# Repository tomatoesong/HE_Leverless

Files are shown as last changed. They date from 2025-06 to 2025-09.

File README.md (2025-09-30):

# HE_Leverless

# 🎮 Hall Effect Fighting Game Controller  

A custom-built **fighting game controller** featuring **Hall effect sensors** based on ESP32-S3 for ultra-durable, low latency performance. Designed for competitive play, modularity, and long-term reliability.  

---

## ✨ Features  

- 🕹 **Hall Effect Sensors** – no wear and tear from metal contact based switches 
- 🔧 **Modular Design** – easily replace buttons, just pull out an switch and snap in a new one
- ⚡ **Low Latency** – optimized input response at over 2000Hz polling with fully customizable actuation points for every switch!
- 🌐 **Web UI** - web based UI for customizing board on the go from anywhere without the need for connecting to a PC
- 💻 **Open Source Firmware** – customizable and community-driven  
- 🎨 **Custom Build** – unique layout and aesthetics  

---

## Custom PCB Layout  

| Front View |
|------------|
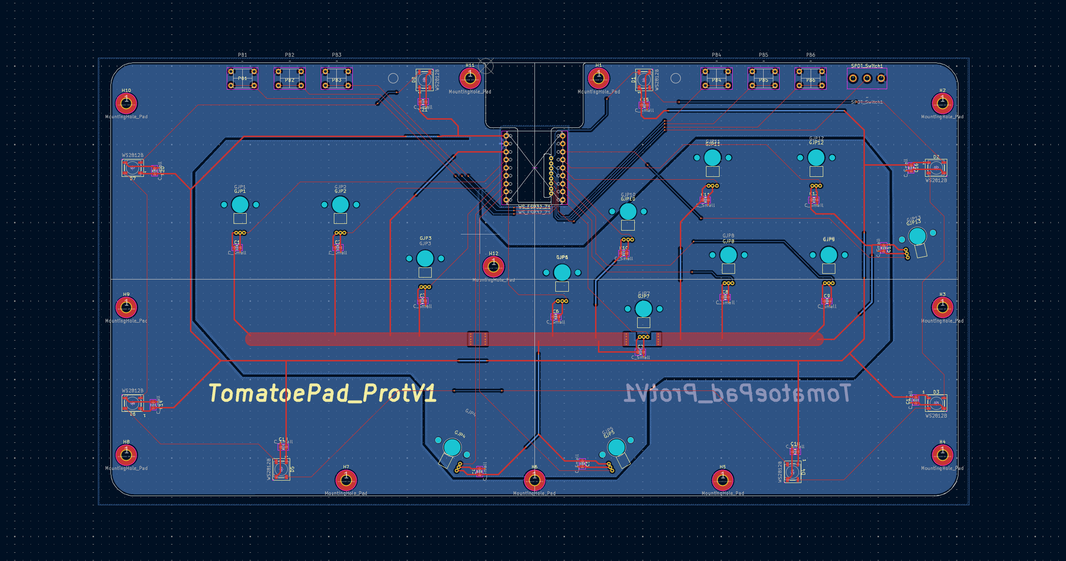
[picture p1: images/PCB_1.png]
|  |

Created Using KiCad and custom library and footprints!

### ✅ PCB Features
- Digital and Analog ground plane seperation
- Low count BOM
- One sided for easy of assembly on hot plate or oven!

---

## Web-Based UI 

| Startup View | Selection | Save with Ease |
|---|---|---|
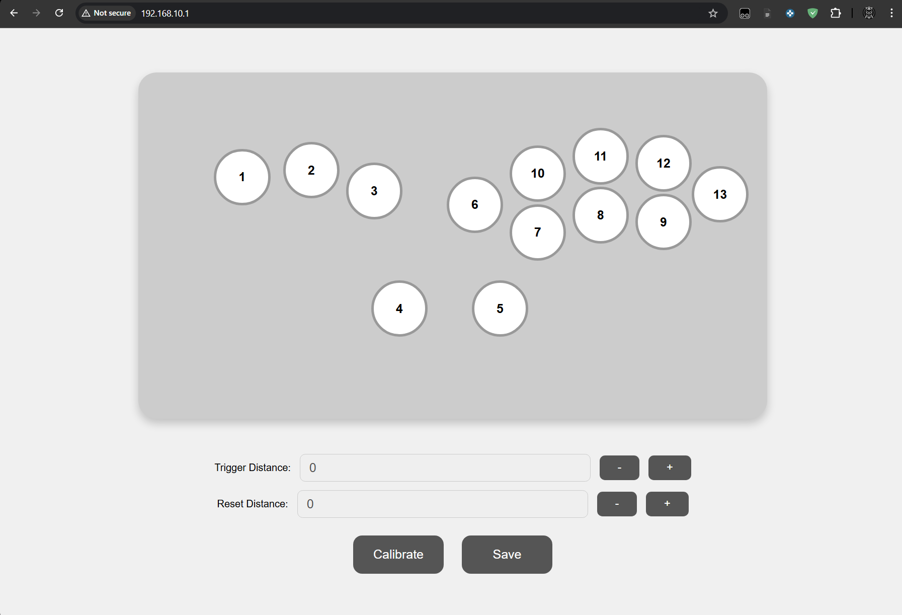
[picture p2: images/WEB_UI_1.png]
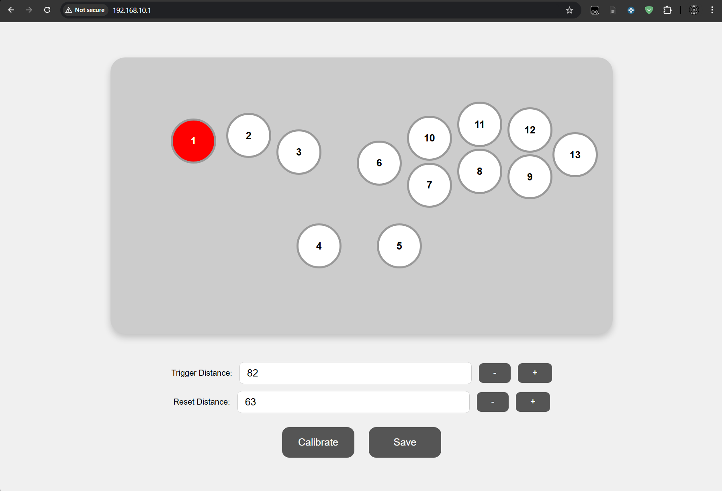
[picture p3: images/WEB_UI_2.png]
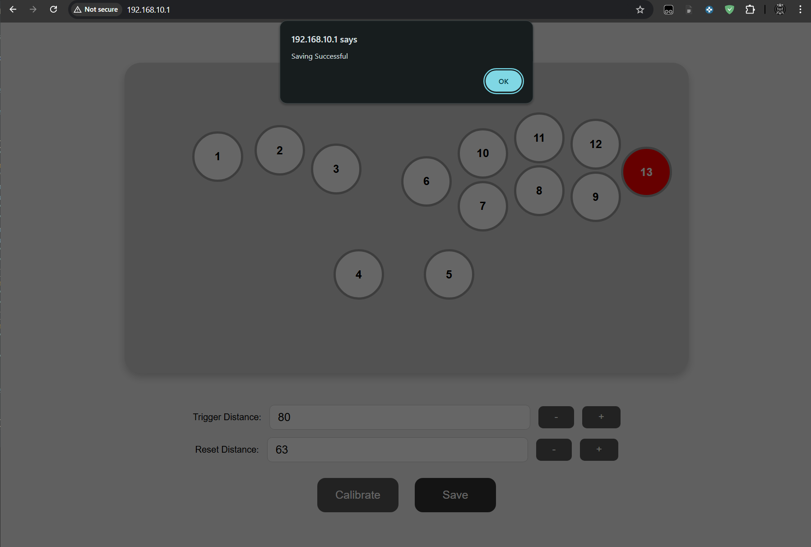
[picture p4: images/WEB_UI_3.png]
|  |  |  |

Fully integrated and interactable WEB UI from an embedded board

### ✅ WEB-UI Features
- Hosts it's own Wifi you connect to
- Access the configurator from any browser at 192.168.10.1
- Individually switch values can be set with intuitive UI indicating what button you are adjusting
- 5 MICRON steps of adjustment for HIGH precision customization

---

## CAD Model  
<!--
| Front View | Inside View | 
|---|---|
| ![Front View](images/CAD_MODEL_1.png) | ![WireFrame View](images/CAD_MODEL_2.png) |

*(Replace the image paths with your actual files, e.g., `/assets/controller-front.png`)*  
-->
| Front View |
|------------|
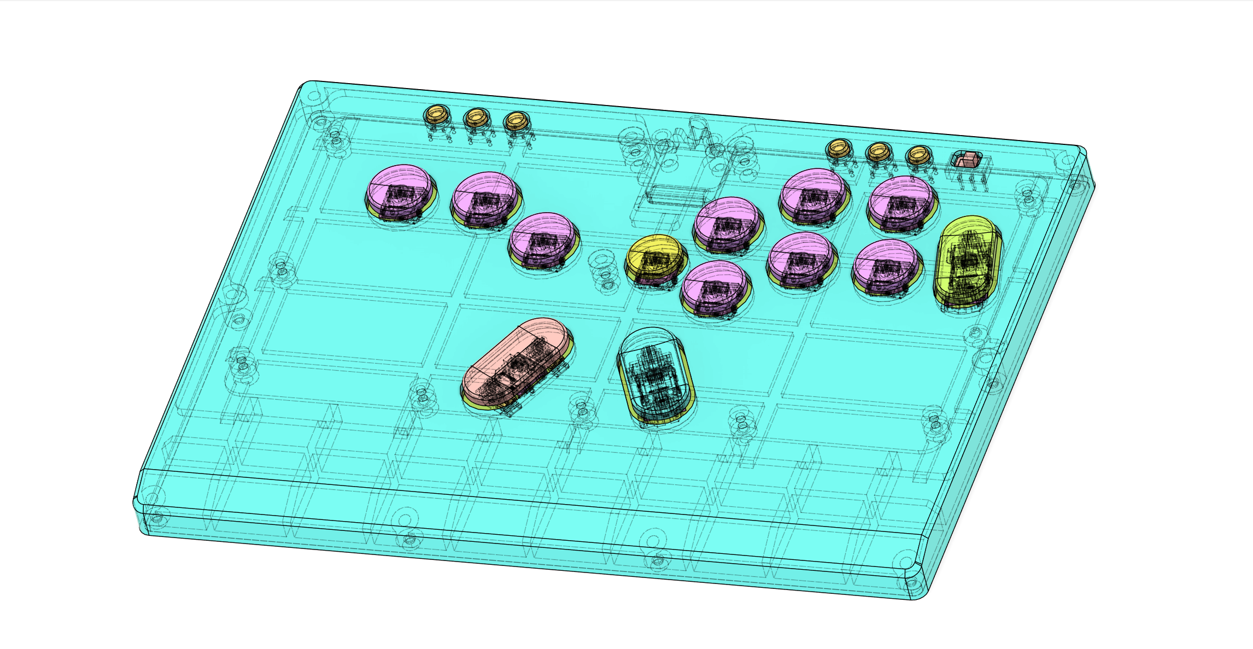
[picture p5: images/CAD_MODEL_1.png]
Front View
|  |

| WireFrame View |
|------------|
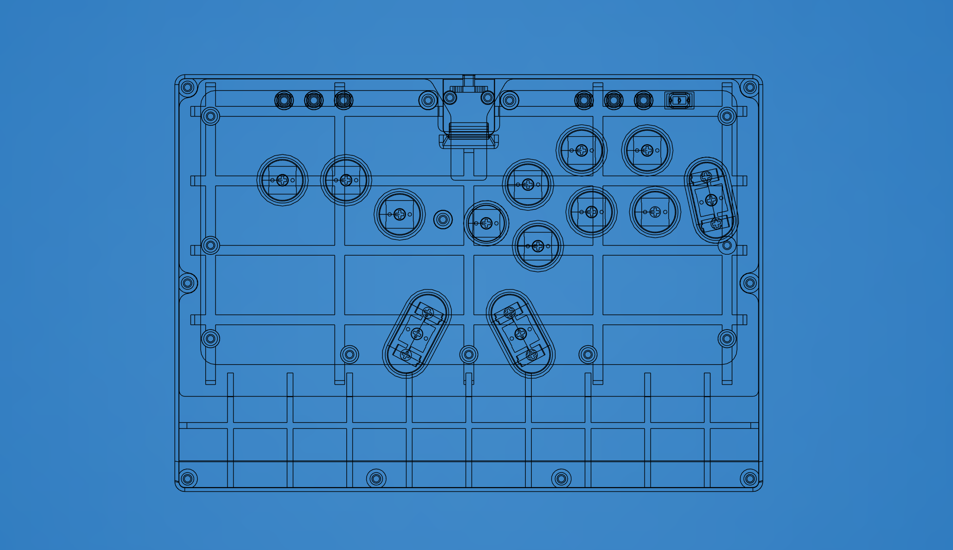
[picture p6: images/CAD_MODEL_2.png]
WireFrame View
|  |

Designed in Fusion360 with all components modeled for accuracy. 

---

## 🚀 Getting Started  

1. Clone this repo:  
   ```bash
   git clone https://github.com/your-username/your-controller-repo.git

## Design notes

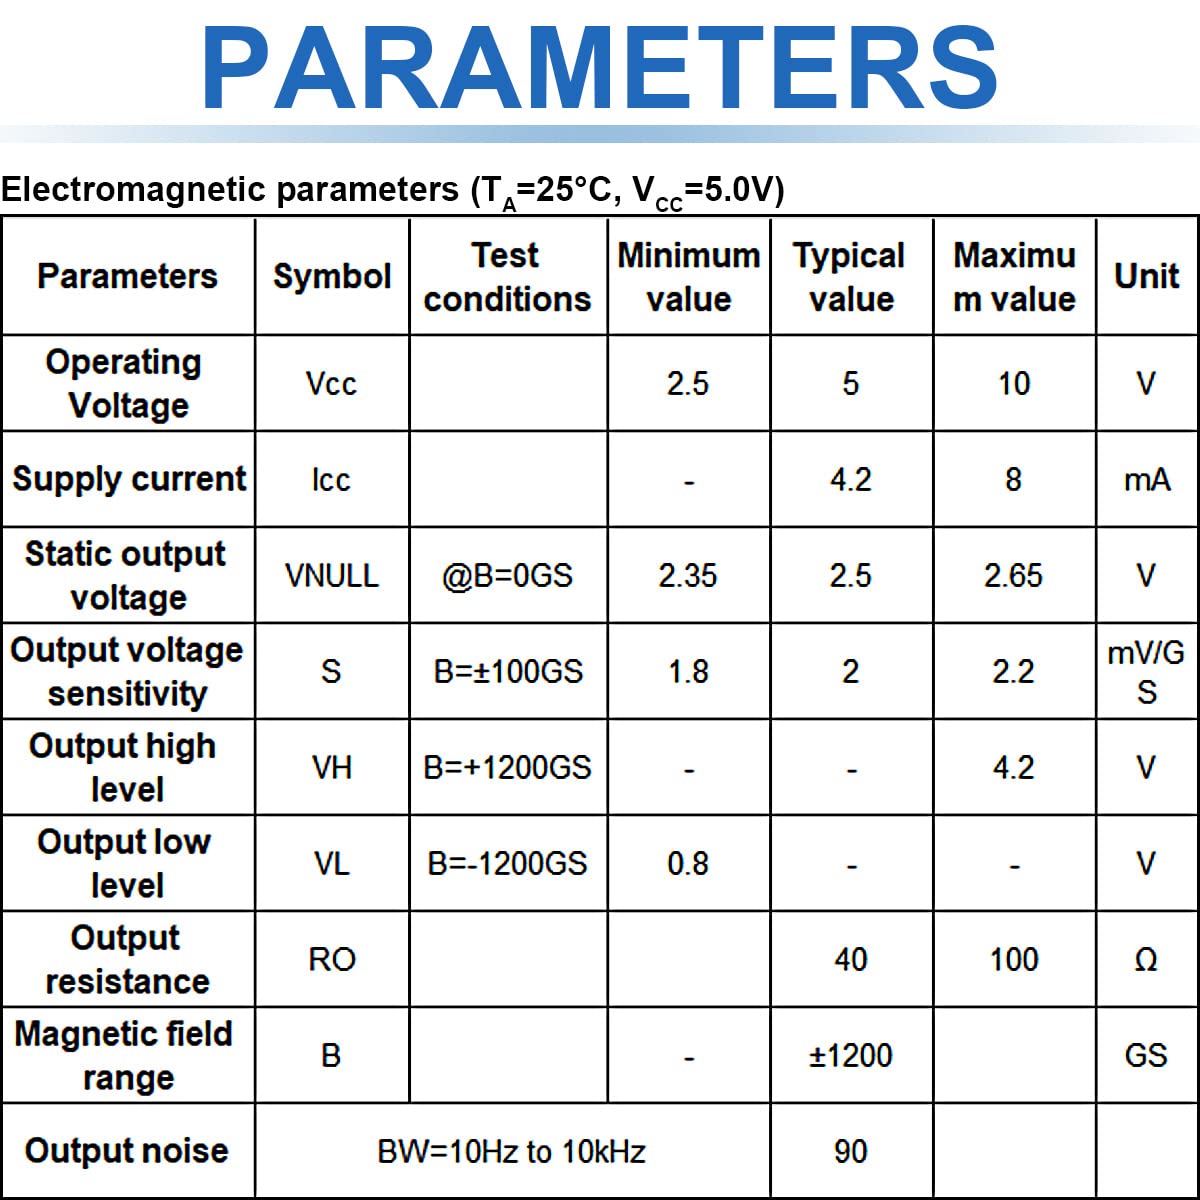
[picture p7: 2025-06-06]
images/71mYZxbhvpL._SL1200_.jpg

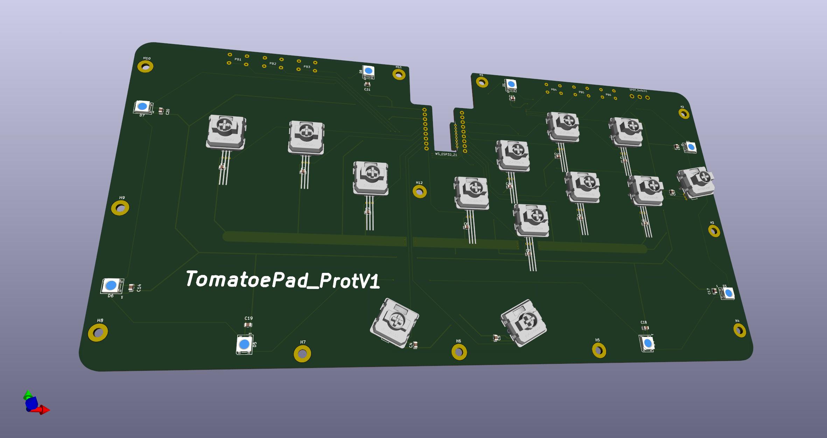
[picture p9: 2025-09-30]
images/HE_Leverless_Mainboard.jpg

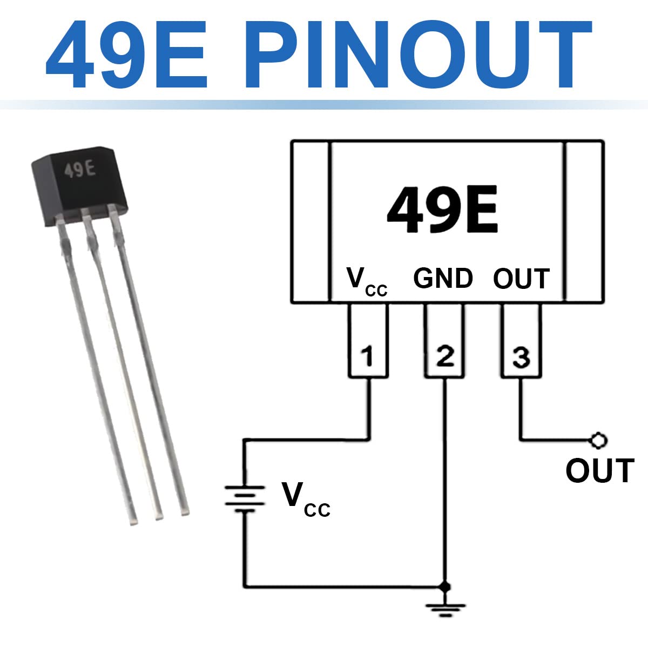
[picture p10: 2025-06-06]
images/51wBsXwjPZL._SL1200_.jpg

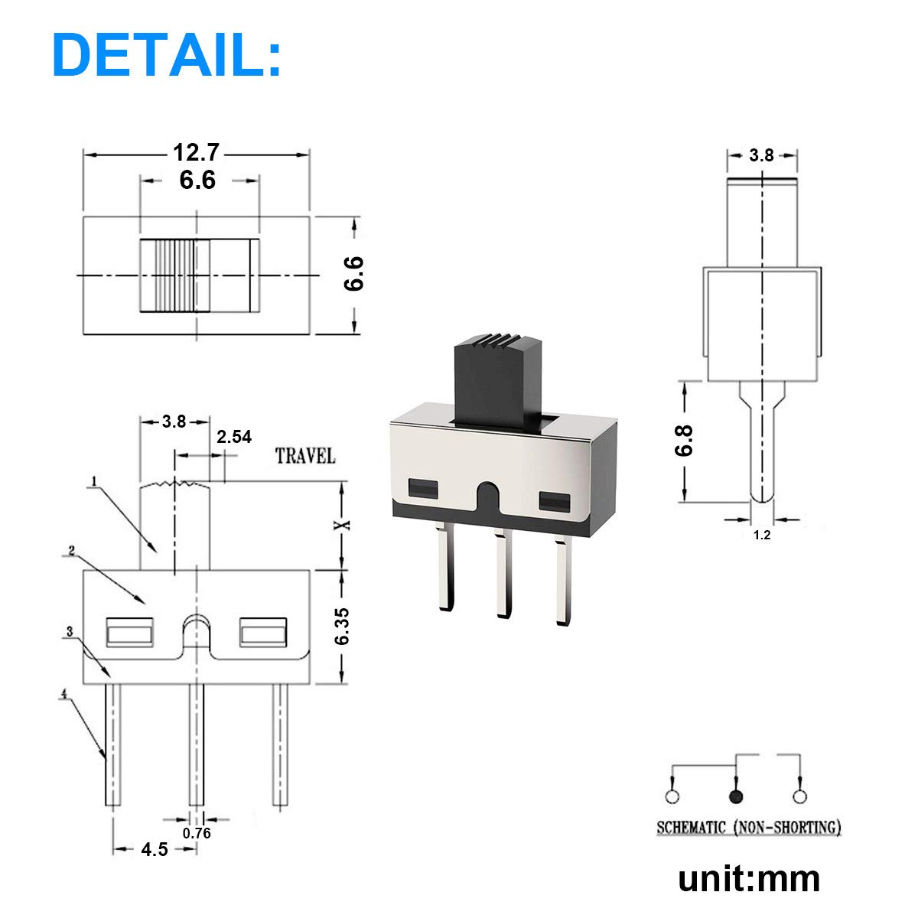
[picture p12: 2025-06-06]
images/61ZuCJ4-nKL._SL1200_.jpg

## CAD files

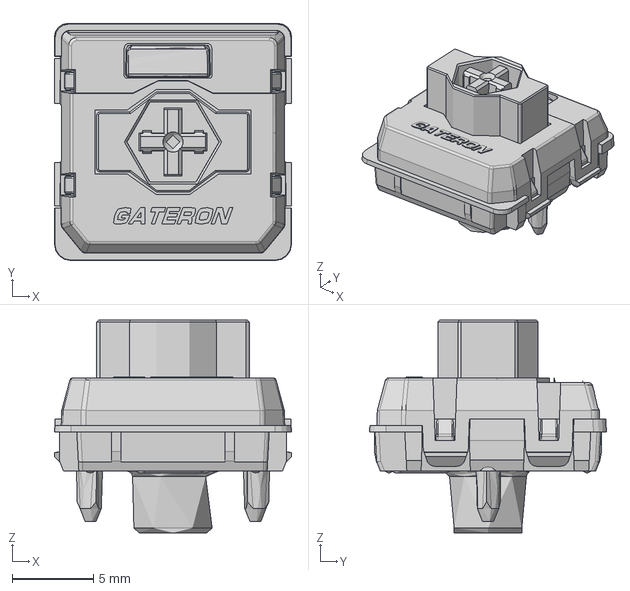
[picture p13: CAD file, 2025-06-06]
HE_Leverless_Mainboard/3DModels/KS-33D-FB 全POM 磁玉Mini矮轴 v3.step
14.6 x 14.6 x 13.1 mm

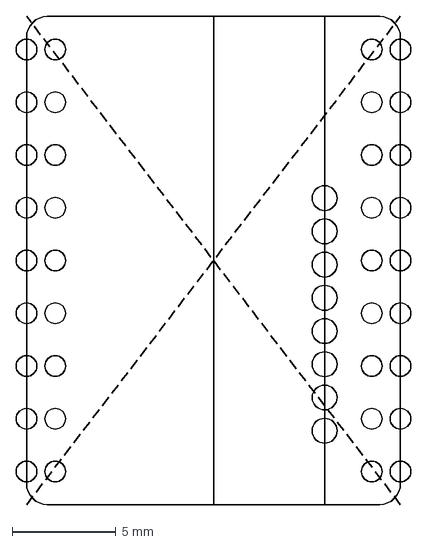
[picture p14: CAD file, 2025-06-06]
WS_ESP32_S3_Zero.dxf
19.0 x 23.5 mm

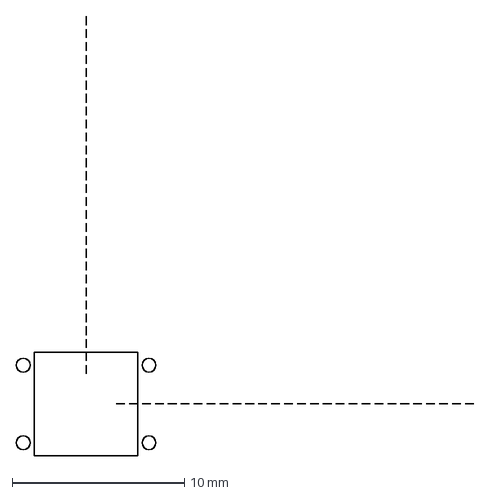
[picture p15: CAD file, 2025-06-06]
6x6_PushButton.dxf
26.6 x 25.5 mm

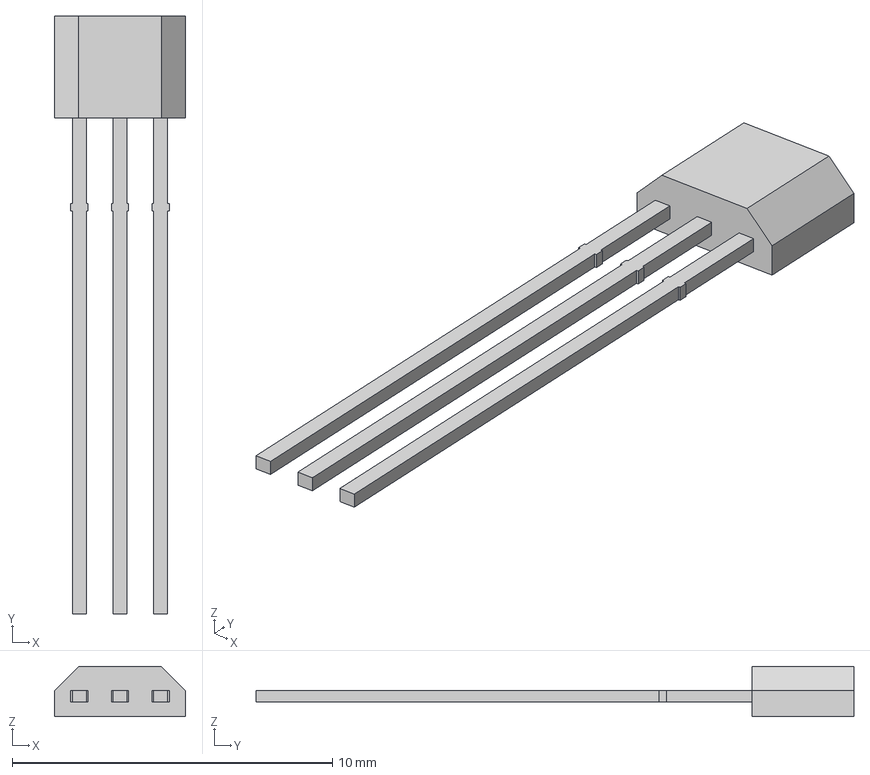
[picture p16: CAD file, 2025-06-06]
HE_Leverless_Mainboard/3DModels/HallEffect_Sensor v1.step
4.10 x 18.7 x 1.57 mm

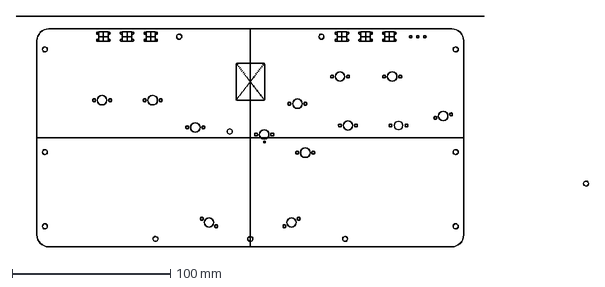
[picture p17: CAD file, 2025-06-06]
PCB.dxf
362.1 x 146.0 mm

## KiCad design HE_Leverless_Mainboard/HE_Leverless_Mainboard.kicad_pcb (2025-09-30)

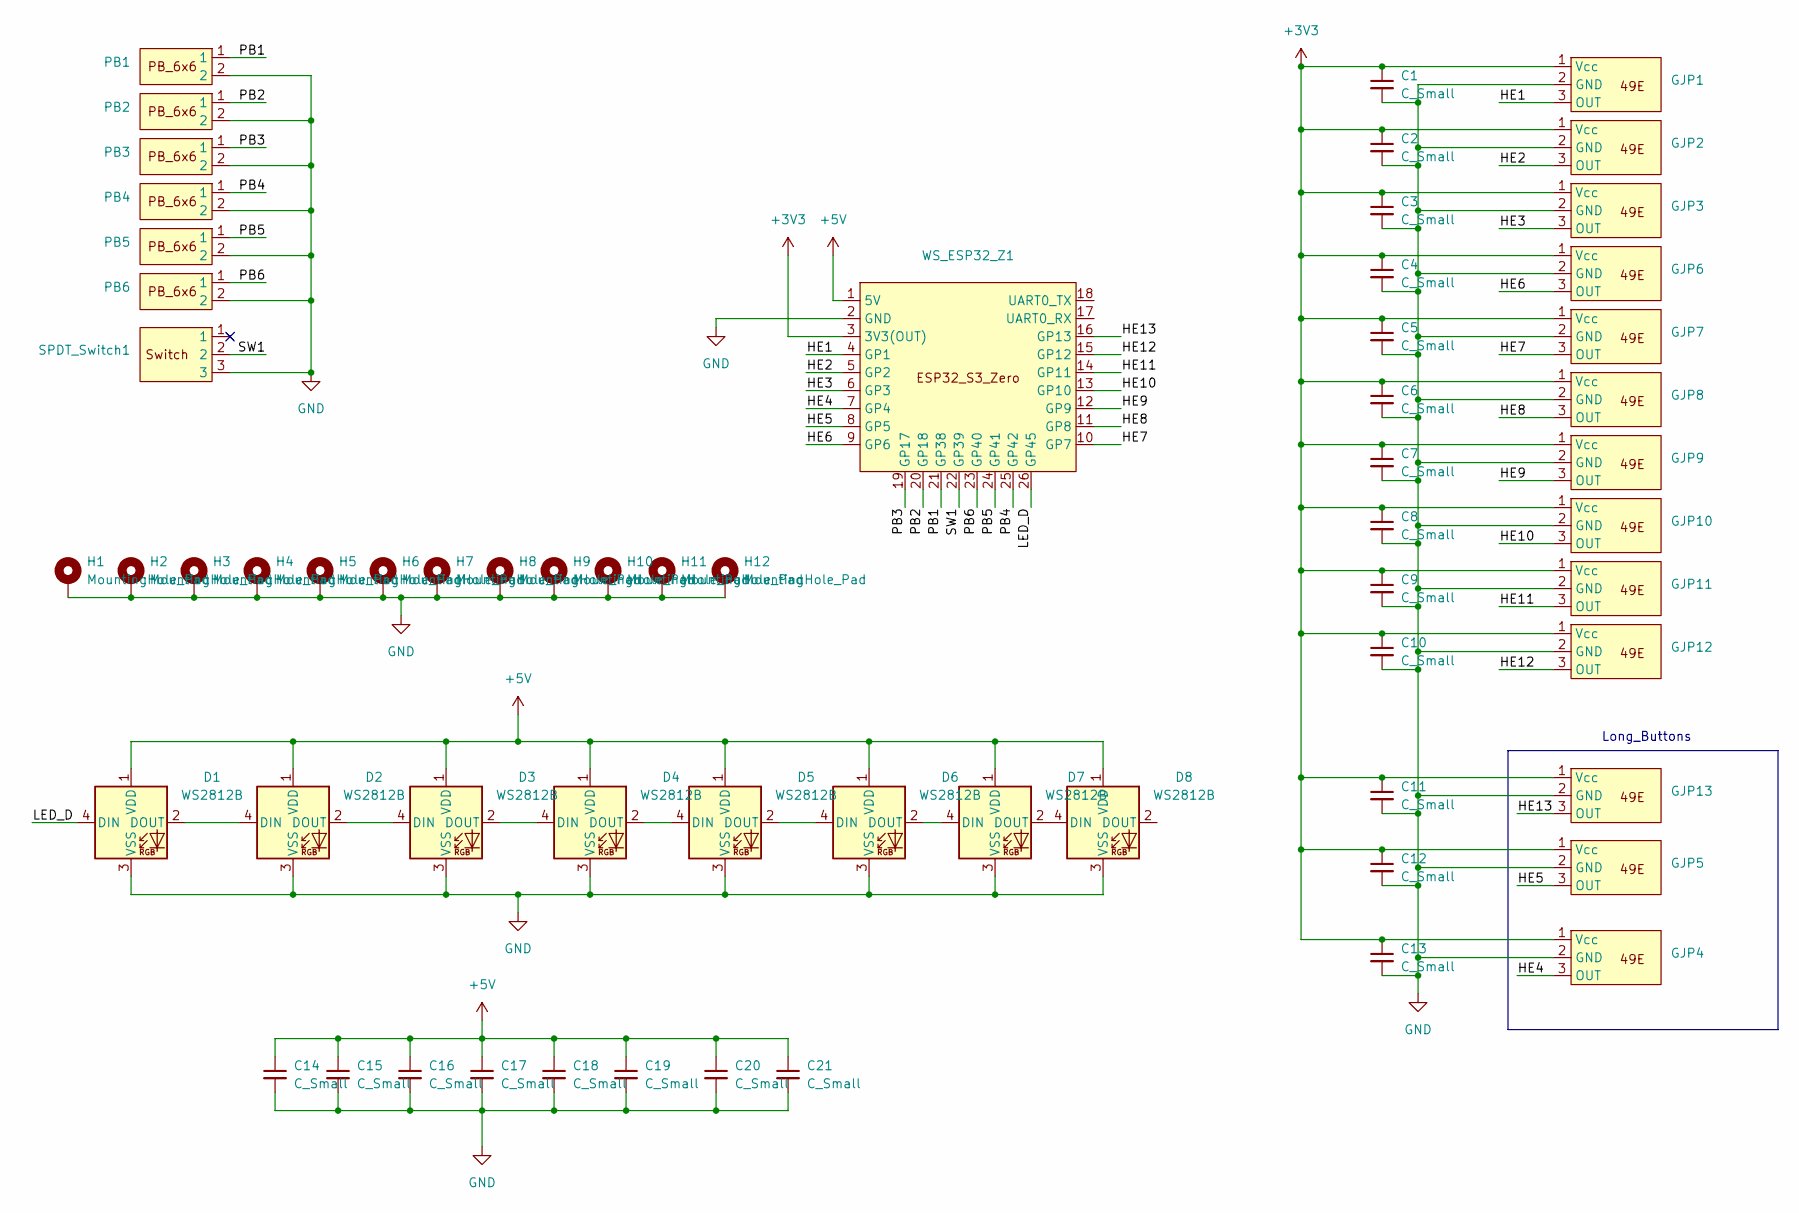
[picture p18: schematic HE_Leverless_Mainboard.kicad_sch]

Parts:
C1, C2, C3, C4, C5, C6, C7, C8, C9, C10, C11, C12, C13, C14, C15, C16, C17, C18, C19, C20, C21: C_Small; C_0805_2012Metric
D1, D2, D3, D4, D5, D6, D7, D8: WS2812B; LED_WS2812B_PLCC4_5.0x5.0mm_P3.2mm
GJP1, GJP2, GJP3, GJP6, GJP7, GJP8, GJP9, GJP10, GJP11, GJP12: Gateron_Jade_Pro
GJP4: Gateron_Jade_Pro_3
GJP5, GJP13: Gateron_Jade_Pro_2
H1, H2, H3, H4, H5, H6, H7, H8, H9, H10, H11, H12: MountingHole_Pad; MountingHole_3.2mm_M3_Pad
PB1, PB2, PB3, PB4, PB5, PB6: 6x6_PushButton
SPDT_Switch1: 1P2T_SPDT_Switch
WS_ESP32_Z1: WS_ESP32_S3_Zero

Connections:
+3V3: C1.1, C2.1, C3.1, C4.1, C5.1, C6.1, C7.1, C8.1, C9.1, C10.1, C11.1, C12.1, C13.1, GJP1.1 (Vcc), GJP2.1 (Vcc), GJP3.1 (Vcc), GJP4.1 (Vcc), GJP5.1 (Vcc), GJP6.1 (Vcc), GJP7.1 (Vcc), GJP8.1 (Vcc), GJP9.1 (Vcc), GJP10.1 (Vcc), GJP11.1 (Vcc), GJP12.1 (Vcc), GJP13.1 (Vcc), WS_ESP32_Z1.3 (3V3(OUT))
+5V: C14.1, C15.1, C16.1, C17.1, C18.1, C19.1, C20.1, C21.1, D1.1 (VDD), D2.1 (VDD), D3.1 (VDD), D4.1 (VDD), D5.1 (VDD), D6.1 (VDD), D7.1 (VDD), D8.1 (VDD), WS_ESP32_Z1.1 (5V)
/HE1: GJP1.3 (OUT), WS_ESP32_Z1.4 (GP1)
/HE2: GJP2.3 (OUT), WS_ESP32_Z1.5 (GP2)
/HE3: GJP3.3 (OUT), WS_ESP32_Z1.6 (GP3)
/HE4: GJP4.3 (OUT), WS_ESP32_Z1.7 (GP4)
/HE5: GJP5.3 (OUT), WS_ESP32_Z1.8 (GP5)
/HE6: GJP6.3 (OUT), WS_ESP32_Z1.9 (GP6)
/HE7: GJP7.3 (OUT), WS_ESP32_Z1.10 (GP7)
/HE8: GJP8.3 (OUT), WS_ESP32_Z1.11 (GP8)
/HE9: GJP9.3 (OUT), WS_ESP32_Z1.12 (GP9)
/HE10: GJP10.3 (OUT), WS_ESP32_Z1.13 (GP10)
/HE11: GJP11.3 (OUT), WS_ESP32_Z1.14 (GP11)
/HE12: GJP12.3 (OUT), WS_ESP32_Z1.15 (GP12)
/HE13: GJP13.3 (OUT), WS_ESP32_Z1.16 (GP13)
/LED_D: D1.4 (DIN), WS_ESP32_Z1.26 (GP45)
/PB1: PB1.1, WS_ESP32_Z1.21 (GP38)
/PB2: PB2.1, WS_ESP32_Z1.20 (GP18)
/PB3: PB3.1, WS_ESP32_Z1.19 (GP17)
/PB4: PB4.1, WS_ESP32_Z1.25 (GP42)
/PB5: PB5.1, WS_ESP32_Z1.24 (GP41)
/PB6: PB6.1, WS_ESP32_Z1.23 (GP40)
/SW1: SPDT_Switch1.2, WS_ESP32_Z1.22 (GP39)
GND: C1.2, C2.2, C3.2, C4.2, C5.2, C6.2, C7.2, C8.2, C9.2, C10.2, C11.2, C12.2, C13.2, C14.2, C15.2, C16.2, C17.2, C18.2, C19.2, C20.2, C21.2, D1.3 (VSS), D2.3 (VSS), D3.3 (VSS), D4.3 (VSS), D5.3 (VSS), D6.3 (VSS), D7.3 (VSS), D8.3 (VSS), GJP1.2 (GND), GJP2.2 (GND), GJP3.2 (GND), GJP4.2 (GND), GJP5.2 (GND), GJP6.2 (GND), GJP7.2 (GND), GJP8.2 (GND), GJP9.2 (GND), GJP10.2 (GND), GJP11.2 (GND), GJP12.2 (GND), GJP13.2 (GND), H1.1, H2.1, H3.1, H4.1, H5.1, H6.1, H7.1, H8.1, H9.1, H10.1, H11.1, H12.1, PB1.2, PB2.2, PB3.2, PB4.2, PB5.2, PB6.2, SPDT_Switch1.3, WS_ESP32_Z1.2 (GND)
unnamed: D1.2 (DOUT), D2.4 (DIN)
unnamed: D2.2 (DOUT), D3.4 (DIN)
unnamed: D3.2 (DOUT), D4.4 (DIN)
unnamed: D4.2 (DOUT), D5.4 (DIN)
unnamed: D5.2 (DOUT), D6.4 (DIN)
unnamed: D6.2 (DOUT), D7.4 (DIN)
unnamed: D7.2 (DOUT), D8.4 (DIN)

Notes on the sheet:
Long_Buttons

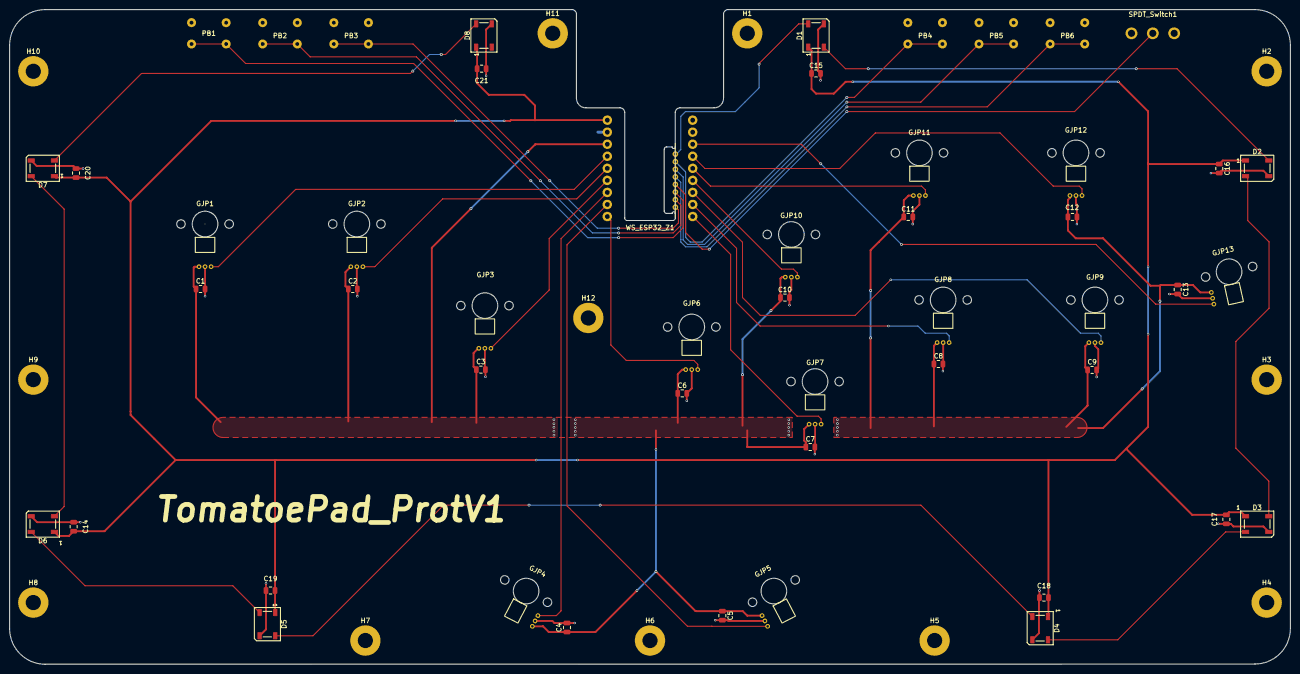
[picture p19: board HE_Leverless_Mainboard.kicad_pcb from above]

Board: 2 copper layers, 270.0 x 138.0 mm, 62 parts (0 on the bottom side), 31 nets.

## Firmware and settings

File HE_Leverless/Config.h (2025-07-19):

#ifndef CONFIG_H_
#define CONFIG_H_

#define RGB_BUILTIN 21

// #define DEBUG_MODE
#define DEADZONE 40
#define DEFAULT_TRIGGER 80
#define DEFAULT_RESET 60

#define ADC_BYTE_SIZE 2
#define LP_BASE_ADDRESS 0
#define HP_BASE_ADDRESS LP_BASE_ADDRESS + pincount * ADC_BYTE_SIZE
#define RT_TRIGGER_ADDRESS HP_BASE_ADDRESS + pincount * ADC_BYTE_SIZE
#define RT_RESET_ADDRESS RT_TRIGGER_ADDRESS + pincount * ADC_BYTE_SIZE

#endif  /* CONFIG_H_ */

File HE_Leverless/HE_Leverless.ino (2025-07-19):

#include "config.h"
#include "usb_helper.h"
#include "calibration.h"
#include "trigger_mode.h"
#include "access_point.h"
#include <EEPROM.h>

bool calibrationMode = false;
bool accessPointMode = false;
Mode mode = RAPID_FIRE_MODE;

void setup() {
  Serial.begin(115200);
  rgbOff();
  // Set up pin as input
  for (uint8_t i = 0; i < pbcount; i++) {
    pinMode(pbpins[i], activeState ? INPUT_PULLDOWN : INPUT_PULLUP);
  }
  if (digitalRead(pbpins[0]) == activeState) {
    calibrationMode = true;
  }
  if (digitalRead(pbpins[5]) == activeState) {
    accessPointMode = true;
    accessPointInit();
  }
  //  EEPROM Setup begin
  EEPROM.begin(ADC_BYTE_SIZE * (pincount * 4 + 10));  // triggerDown and triggerUp plus 10 extra
  load_calib_data();
  load_lastPos();
  load_RT_data();

  //  USB Setup begin
  init_hid();

  // fillArrayWith(rT_Triggers, DEFAULT_TRIGGER, pincount);      //REMOVE THIS LATER!!!
  // fillArrayWith(rT_ResetDistances, DEFAULT_RESET, pincount);  //REMOVE THIS LATER!!!
  // fillArrayWith(lastPos, 1900, pincount);                     //REMOVE THIS LATER!!!
}

void loop() {
  if (accessPointMode) {
    while (1) {
      wifiProtocol();
    }
  }
  if (!calibrationMode) {
    switch (mode) {
      case RAPID_FIRE_MODE:
        {
          //  State Machine Method
          for (uint8_t i = 0; i < pincount; i++) {
            uint16_t nowPos = analogRead(pins[i]);
            if (nowPos < (highestPoints[i] - DEADZONE)) {
              int keyDelta = nowPos - lastPos[i];
              switch (buttonState[i]) {
                case 0:  //Pressing State
                  if ((-keyDelta) > rT_Triggers[i]) {
                    //Key Press
                    keys |= 1 << i;
                    buttonState[i] = 1;
                  }
                  if (keyDelta > 25) {
                    lastPos[i] = nowPos;
                  }
                  // Serial.printf("State: %d, nowPos: %d, lastPos: %d, delta: %d\n", buttonState[0], nowPos, lastPos[0], keyDelta);
                  break;
                case 1:  //Releaseing State
                  if (keyDelta > rT_ResetDistances[i]) {
                    //Key Release
                    keys &= ~(1 << i);
                    buttonState[i] = 0;
                  }
                  if (keyDelta < -25) {
                    lastPos[i] = nowPos;
                  }
                  // Serial.printf("State: %d, nowPos: %d, lastPos: %d, delta: %d\n", buttonState[0], nowPos, lastPos[0], keyDelta);
                  break;
              }
            } else {
              keys &= ~(1 << i);
            }
          }
        }
        break;
      case CONTINOUS_MODE:
        break;
      default:
        for (uint8_t i = 0; i < pincount; i++) {
          keys = (keys & ~(1 << i)) | (analogRead(pins[i]) < rT_Triggers[i]) << i;
        }
        break;
    }
    switch (controller_mode) {
      case GAMEPAD:
        gamepad_process_hid();
        break;
      case KEYBOARD:
        keyboard_process_hid();
        break;
    }
    // printKeys();
    // Serial.println(EEPROM.readULong(120));
  } else {
    delay(500);
    Serial.println("Calibrating....");
    getHighestPoints();
    getLowestPoints();
    save_calib_Data();
    while (1) {
      printHigest();
      printLowest();
      delay(1000);
    }
  }
}

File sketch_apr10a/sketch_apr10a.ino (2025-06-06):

#include <EEPROM.h>
#include "esp_adc/adc_oneshot.h"

unsigned long lastTime;
unsigned long totalTime;


uint16_t adcVal[101];

adc_oneshot_unit_handle_t adc1_handle;
adc_oneshot_unit_init_cfg_t init_config1 = {
    .unit_id = ADC_UNIT_1,
    .ulp_mode = ADC_ULP_MODE_DISABLE,
};
adc_oneshot_chan_cfg_t config = {
  .atten = ADC_ATTEN_DB_12,
  .bitwidth = ADC_BITWIDTH_DEFAULT,
};

void setup() {
  // Initialize serial communication at 115200 bits per second:
  Serial.begin(115200);

  // Optional for ESP32: Set the resolution to 9-12 bits (default is 12 bits)
  analogContinuousSetWidth(12);

  // Optional: Set different attenaution (default is ADC_11db)
  analogContinuousSetAtten(ADC_11db);
  lastTime = micros();
  while (!Serial) {
  }
  uint8_t* ad = 0x00;
  EEPROM.begin(3);
  Serial.printf("EEPROM 0x00 ~ 0x02: %d, %d, %d", EEPROM.read(0), EEPROM.read(1), EEPROM.read(2));
}

void loop() {
  // Check if conversion is done and try to read data
  // for (int i = 0; i < 13; i++) {
  //   if (i == 1) lastTime = micros();
  //   adcVal[i] = analogRead(i);
  // }
  lastTime = micros();
  adcVal[0] = analogRead(1);
  adcVal[1] = analogRead(2);
  adcVal[2] = analogRead(3);
  adcVal[3] = analogRead(4);
  adcVal[4] = analogRead(5);
  adcVal[5] = analogRead(6);
  adcVal[6] = analogRead(7);
  adcVal[7] = analogRead(8);
  adcVal[8] = analogRead(9);
  adcVal[9] = analogRead(10);
  adcVal[10] = analogRead(11);
  adcVal[11] = analogRead(12);
  adcVal[12] = analogRead(13);
  totalTime = micros() - lastTime;
  Serial.printf("  Total Time: %d \n adc[12]: %d", totalTime, adcVal[11]);
  delay(333);
}

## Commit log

2025-06-12 Mass UPDATE
    - Massive organization overhaul
    - Added Rapid Trigger function
    - Calibration Protocol added
2025-07-19 WebUI updated
    TO-DO: Add calibration sequence to WebUI
2025-09-25 Updated PCB
    [HE_Leverless_MB_V2.kicad_pcb, HE_Leverless_MB_V2.kicad_sch]
2025-09-30 Added images
    [HE_Leverless_Mainboard.kicad_pcb, HE_Leverless_Mainboard.kicad_sch]
